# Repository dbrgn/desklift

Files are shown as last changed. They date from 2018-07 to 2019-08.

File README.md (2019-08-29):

# desklift

A simple PCB to control an Actiforce desk lift from a Blue Pill STM32
microcontroller board using two low-current relays.

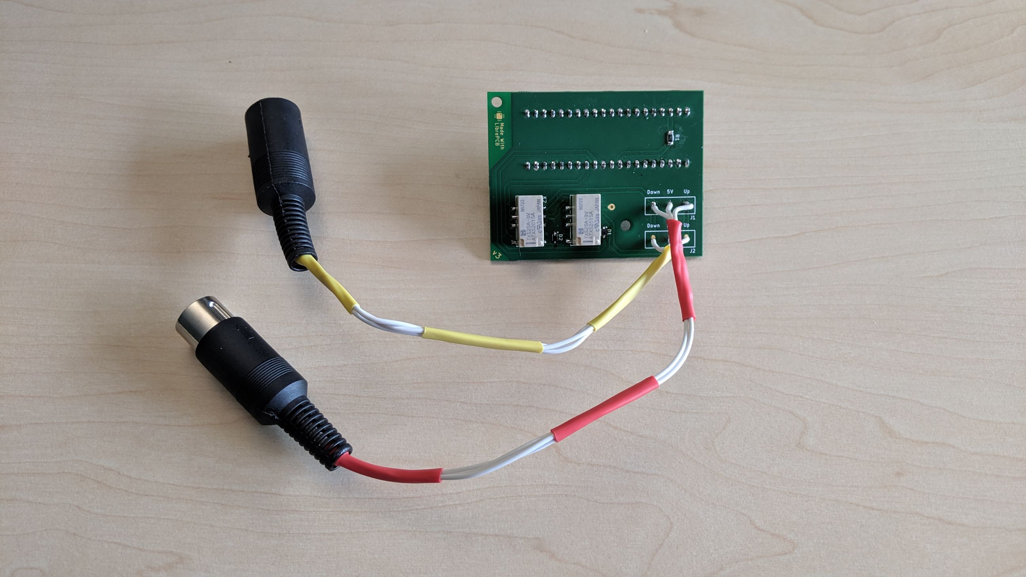
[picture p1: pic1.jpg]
Picture 1: Front


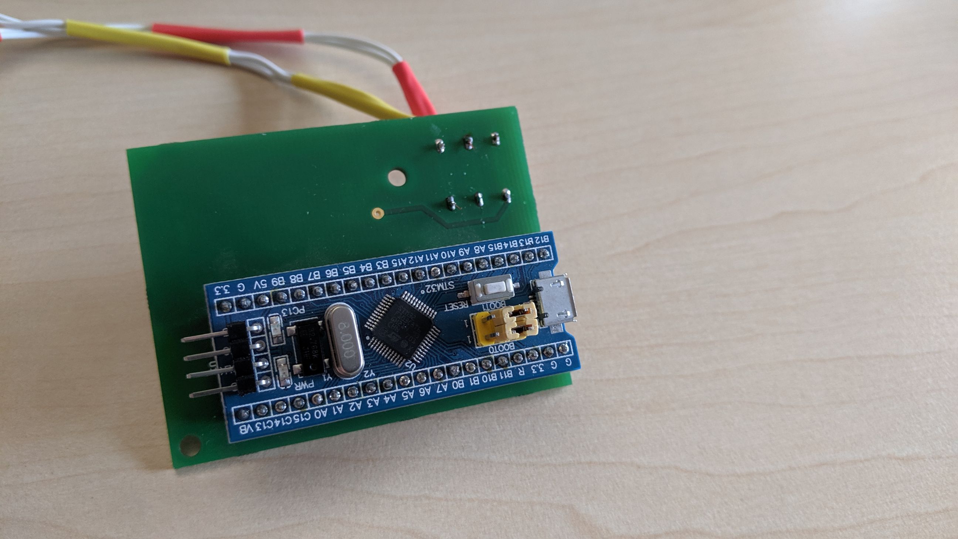
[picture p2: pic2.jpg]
Picture 2: Back


The PCB itself is designed mostly one-sided, you just need a single jumper wire
if you want a one-sided board. This makes it suitable for self-etching.

You can order the PCB [on Aisler](https://aisler.net/p/MNKNKKFU).

This is a [LibrePCB](http://librepcb.org) project!

## BOM

| Designator | Description | MPN | Approx. Cost |
| --- | --- | --- | --- |
| U1 | [STM32F103 "Blue Pill"](https://www.embedded-tools.ch/boards/stm/247/stm32f103c8t6-blue-pill-eval-board) | | 5.50 CHF |
| U1 | [Socket Strip 1x20](https://de.aliexpress.com/item/32996229462.html) | | 0.74 USD |
| K1, K2 | [Relay 3V 16.7mA](https://www.digikey.ch/product-detail/de/panasonic-electric-works/TXS2SA-3V/255-2341-5-ND/650160) | TXS2SA-3V | 4.56 CHF |
| J1 | [7-Pin DIN 45329 Connector M](https://de.aliexpress.com/item/32860020971.html) | | 0.37 USD |
| J2 | [7-Pin DIN 45329 Connector F](https://de.aliexpress.com/item/32860020971.html) | | 0.42 USD |
| D1, D2 | [Diode Schottky 30V 500mA](https://www.digikey.ch/product-detail/de/on-semiconductor/NSR0530HT1G/NSR0530HT1GOSCT-ND/5761654) | NSR0530HT1G | 0.16 CHF |
| R1 | Resistor 1.8K 3216 (1206) | | 0.02 CHF |
| PCB | [Printed Circuit Board](https://aisler.net/p/MNKNKKFU) | | 7.50 CHF |

Total material cost: ~24 USD

## License

See [LICENSE.txt](LICENSE.txt).

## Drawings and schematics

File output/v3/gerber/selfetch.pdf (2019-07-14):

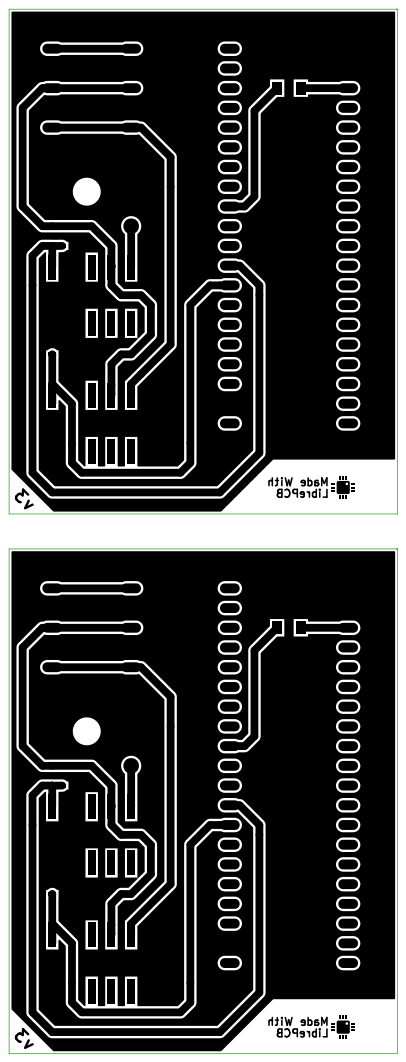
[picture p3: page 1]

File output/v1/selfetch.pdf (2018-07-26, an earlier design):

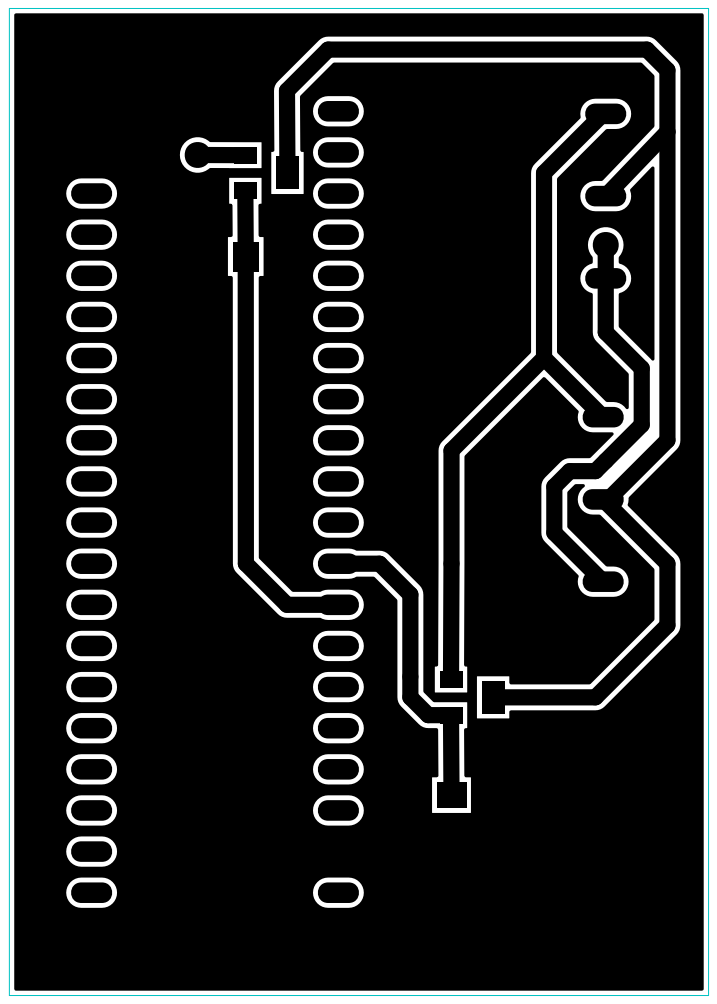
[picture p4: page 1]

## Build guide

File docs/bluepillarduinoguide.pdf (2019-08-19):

# STM32F103C8T6 Blue pill Arduino guide

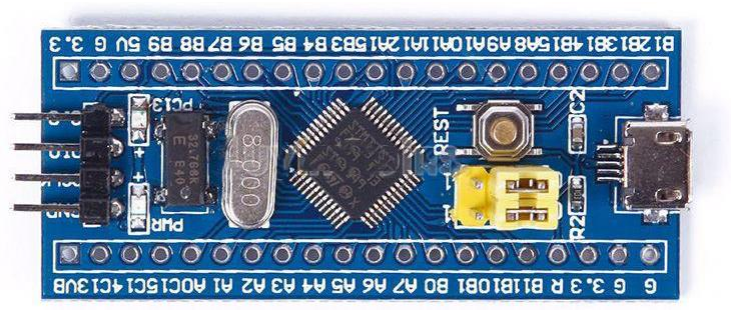
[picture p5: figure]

For beginners it might be difficult to use the popular and cheap blue pill board based on STM32F103C8T6. It’s because using an embedded development tools like KEIL isn’t easy for beginners. This 32 bit microcontroller based on ARM Cortex-M3 architecture is far better than your traditional arduino board.

You can compare it to Arduino DUE but it has got a very small size like the arduino Nano. There’s lack of proper documentation on it and everything available in the internet is quite scattered. So, here’s something to get you started easily.

## STEPS:

1. First download all the resources from this mediafire link. (http://www.mediafire.com/file/3h9gcih1budfhiz/resource_STM32_bluepill.zip) The password for extracting data from the zip file is: techshopbd.
2. Open resource STM32 bluepill folder. Copy the Arduino_STM32 folder to your sketchbook folder/hardware. Go to arduino IDEs file>preferences and you’ll find the location of your sketchbook folder. If there’s no hardware folder, create one named as “hardware” (all lowercase letter).Your arduino IDE is now ready for Blue pill.
3. Have a look on the pinout diagram on the next page. There are 2 yellow colored jumpers beside the usb port. They are boot options. Connect boot0 pin to 3V3 and boot1 pin to GND to start the board in SPI mode when it’s powered up or the reset button is pressed.
4. Now connect a FTDI board (FT232RL) to blue pill. You can use any of this (https://www.techshopbd.com/product-categories/breakout-boards/1771/ftdi-basic-breakout-3-3v-techshop-bangladesh) or this (https://www.techshopbd.com/product-categories/modules-98775/2621/ftdi-usb-to-serial-converter-3v3-5v-techshop-bangladesh) or this. (https://www.techshopbd.com/product-categories/modules-98775/2622/ftdi-usb-to-serial-converter-3v3-techshop-bangladesh) Connect FTDI TX to blue pill RX1 (PA10) and FTDI RX to blue pill TX1(PA9).
5. Connect GND. If your FTDI power pin is 5V, connect it to the 5v pin of Blue pill board. If it’s 3.3 volt, connect to the pin marked as 3.3. Connecting 5v to any 3.3v pin of Blue pill board will permanently damage it.

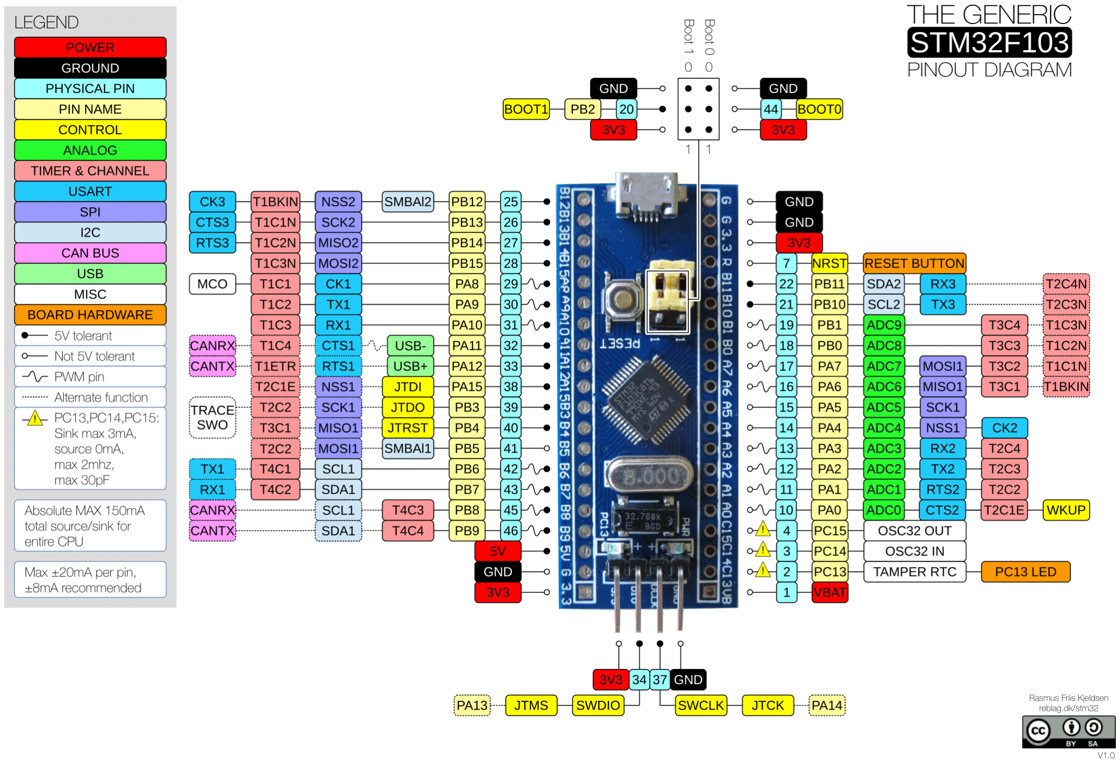
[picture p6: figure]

6. Connect the FTDI board to your PC using USB port. You must install the FTDI driver to your PC to use the FTDI board. You’ll find enough resources on the internet on this. FYI, it’s the driver for arduino Nano.
7. Close arduino IDE if it’s open. Then open it. Go to Tools>board> Generic STM32F103C Series. Then go to Tools>Variant>STM32F103C8T6(20k ram, 64k flash). These new options for STM32 will be automatically added to arduino if you’ve performed everything described it step 2 successfully.
8. Go to tools> upload method>serial. Then tools>port and select the port of the FTDI.
9. Go to tools>board> Boards manager and check if “Arduino SAM Boards (32 bit ARM Cortex M3)” is installed or not. If not, select more info and an install button will appear. Install the board definitions. It’s necessary because codes for the Blue pill board uses some files written for Arduino Duo for successful compilation.
10. Now open the blink code from File>Examples>Basic>blink. Press the reset button on the Blue pill board and hit upload button on the Arduino IDE. (board built-in LED is on PC13)
11. Note that you have to reset the Blue pill board every time you are about to upload code.

12. You will find all other Examples for the Blue pill board under Up button beneath tools option>hardware>Arduino_STM32.

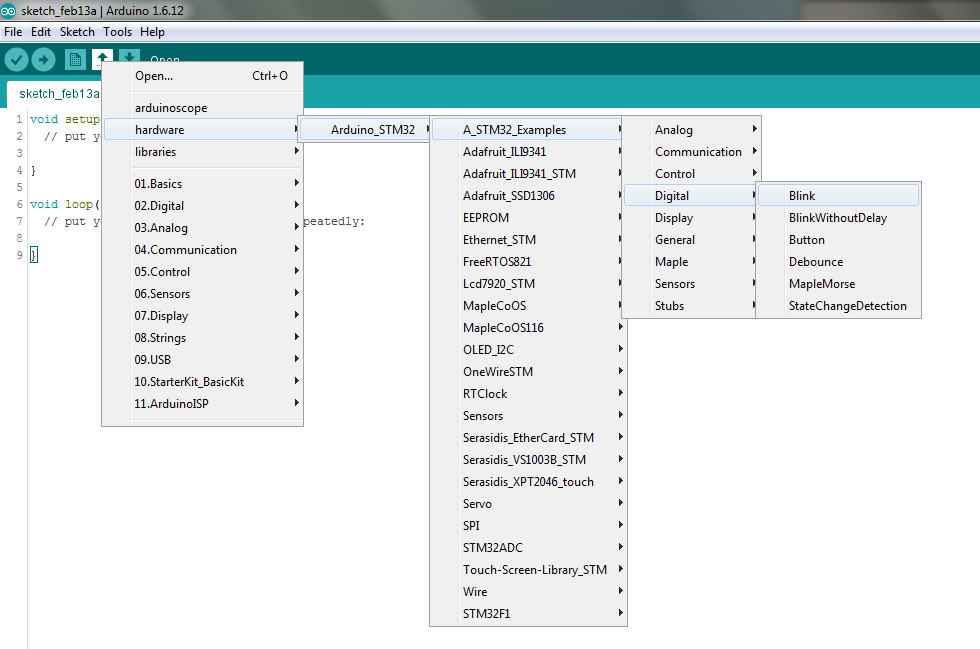
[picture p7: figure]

Note that, your code will stop working as soon as you restart or reset the blue pill board. You have to connect boot0 pin to GND using the jumper after uploading code to watch your code working. But you cannot upload code using USAR1 when boot0 is connected to GND. So,

1. Every time before uploading code, connect boot0 to 3V3 and press the reset button
2. When done with code uploading, connect boot0 to GND.

Uploading program directly to flash:

If you don’t want to use FTDI to upload code and use the microusb port of the blue Pill board instead, you have to flash a bootloader inside the STM32F103C8T6. By doing so, you don’t have to connect boot0 pin to 3v3 for uploading code. And there will be no need to press the RESET button every time before uploading a code.

1. Download demonstrator gui (STM32 flasher) from this link. (http://www.st.com/en/development-tools/flasher-stm32.html) You have to create a free account to download. Install the software when downloaded.
2. Keep your blue Pill board connected to PC via the FTDI and keep boot0 pin connected to 3V3. Press the RESET button.
3. Open STMFlashLoader Demo (demonstrator gui) executable file. Select 115200 Baud rate and select the FTDI COM port. Leave all other settings as default.
4. Press NEXT and It will automatically detect the blue pill.

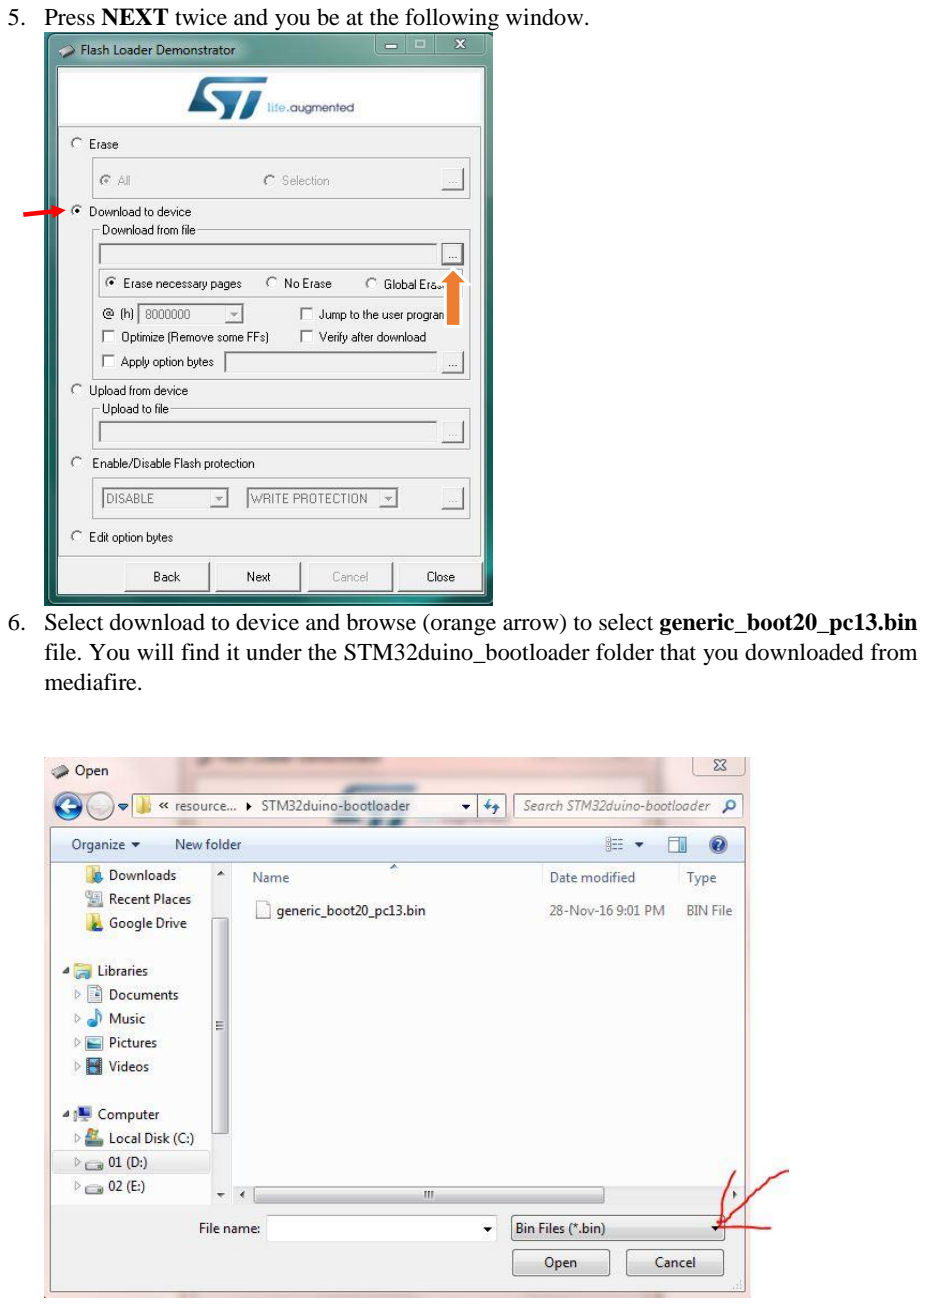
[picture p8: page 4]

5. Press NEXT twice and you be at the following window.
6. Select download to device and browse (orange arrow) to select generic_boot20_pc13.bin file. You will find it under the STM32duino_bootloader folder that you downloaded from mediafire.

7. Select Bin Files (red arrow) if the bootloader file doesn’t show up. Press Open.
8. Press NEXT when the bootloader file is loaded and the file will be downloaded to Blue pill board. Close demonstrator gui (STM32 flasher) when done.
9. Open your arduino sketchbook folder. Then open Arduino_STM32 folder>drivers>win and run “install_drivers.bat” as administrator (right click on file, then select run as administrator). Press any key to close when done.
Then run “install_STM_COM_drivers.bat” as administrator, too.
10. Connect boot0 to GND, disconnect FTDI board and connect a microUSB cable (android data cable) to Blue pill. Press the RESET button before connecting to PC.
11. You’ll find windows installing driver for the Blue pill when you connect it to PC using the on board microUSB. Eventually a driver named as “maple DFU” will be installed. You can find it inside windows Device Manager>libusb>maple DFU. Note that there will be no COM port assigned to Blue pill board. That’s normal.
12. Open arduino IDE. Go to Tools>board> Generic STM32F103C Series. Then go to Tools>Variant>STM32F103C8T6 (20k ram, 64k flash). Go to tools> upload
method>STM32duino | bootloader. | Now | open | the | blink | code | from
File>Examples>Basic>blink.
13. Go to tools>port and make sure no port is selected or the port option is deactivated.
14. Hit the upload button. As soon as “uploading” message appears at the bottom of arduino IDE, press the RESET button of Blue pill board.
15. If your code uploads successfully, you’ll find that windows is installing a new driver and this time it will assign a COM port for your Blue pill board.
16. Go to tools>port and select the correct COM port for Blue pill. The COM port can be found on windows Device Manager> ports (COM & LPT)> Maple Serial (correct port).
17. You have to make sure that the correct COM port is selected to ensure code uploading from now on.

The STM32duino bootloader is called perpetual bootloader. It works on DFU mode at first without using any COM port. After the first program is uploaded, it assigns COM port for the computer.

18. You are now ready to use Blue pill board as normal arduino board by using the on board microUSB. Keep Boot0 and Boot1 pin always connected to GND. You don’t have to press RESET button while uploading code anymore.

Video Resources:
www.youtube.com/watch?v=Ze6q6NidS5w www.youtube.com/watch?v=0jdJp3TQuJY

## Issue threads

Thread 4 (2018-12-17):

Implement USB support

dbrgn, 2018-12-17:
...using https://github.com/mvirkkunen/stm32f103xx-usb

dbrgn, 2019-08-18:
Replaced by https://github.com/stm32-rs/stm32-usbd

Closed 2019-08-21.

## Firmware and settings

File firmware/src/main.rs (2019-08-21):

//! Desk lift firmware
//!
//! Serial protocol:
//!
//! - Baudrate 115'200
//! - Every command is a single signed byte
//! - Positive values move up, negative values move down
//! - The value must be multiplied by 10 ms to get the move duration
//!
//! Physical wiring:
//!
//! - Serial communication over USART1 (PB6, PB7)
//! - "Up" connected to PB4
//! - "Down" connected to PB5

#![deny(unsafe_code)]
#![no_main]
#![cfg_attr(not(test), no_std)]

// Panicking behavior
#[cfg(not(feature = "debug"))]
extern crate panic_halt; // you can put a breakpoint on `rust_begin_unwind` to catch panics
#[cfg(feature = "debug")]
extern crate panic_semihosting; // logs messages to the host stderr; requires a debugger

// Debug logging
#[cfg(feature = "debug")]
use cortex_m_semihosting::hprintln;

use cortex_m::asm::delay;
use embedded_hal::digital::v2::OutputPin;
use rtfm::app;
use stm32_usbd::{UsbBus, UsbBusType};
use stm32f1xx_hal::{prelude::*, pac};
use stm32f1xx_hal::delay::{Delay};
use stm32f1xx_hal::gpio::{Output, PushPull, OpenDrain, State, gpiob, gpioc};
use usb_device::bus;
use usb_device::device::UsbDevice;
use usb_device::prelude::{UsbDeviceBuilder, UsbVidPid};
use usbd_serial::{SerialPort, USB_CLASS_CDC};

use desklift_command::{Command, Direction};

const ERRNO_GPIO_UPDN: u8 = 1;
const ERRNO_GPIO_LED: u8 = 2;
const ERRNO_GPIO_DEBUG: u8 = 3;

const VERSION: &str = env!("CARGO_PKG_VERSION");

#[app(device = stm32f1::stm32f103)]
const APP: () = {
    // GPIO pins
    static mut GPIO_UP: gpiob::PB4<Output<PushPull>> = ();
    static mut GPIO_DOWN: gpiob::PB5<Output<PushPull>> = ();

    // LED pins
    static mut LED: gpioc::PC13<Output<OpenDrain>> = ();

    // Delay peripheral
    static mut DELAY: Delay = ();

    // USB
    static mut USB_DEV: UsbDevice<'static, UsbBusType> = ();
    static mut USB_SERIAL: SerialPort<'static, UsbBusType> = ();

    /// Initialiation happens here.
    ///
    /// The init function will run with interrupts disabled and has exclusive
    /// access to Cortex-M and device specific peripherals through the `core`
    /// and `device` variables, which are injected in the scope of init by the
    /// app attribute.
    #[init]
    fn init() {
        static mut USB_BUS: Option<bus::UsbBusAllocator<UsbBusType>> = None;

        #[cfg(feature = "debug")]
        hprintln!("init").unwrap();

        // Cortex-M peripherals
        let core: rtfm::Peripherals = core;

        // Device specific peripherals
        let device: pac::Peripherals = device;

        // Get reference to peripherals required for USART
        let mut rcc = device.RCC.constrain();
        let mut afio = device.AFIO.constrain(&mut rcc.apb2);
        let mut gpioa = device.GPIOA.split(&mut rcc.apb2);
        let mut gpiob = device.GPIOB.split(&mut rcc.apb2);
        let mut gpioc = device.GPIOC.split(&mut rcc.apb2);
        let mut flash = device.FLASH.constrain();
        let clocks = rcc
            .cfgr
            .use_hse(8.mhz())
            .sysclk(48.mhz())
            .pclk1(24.mhz())
            .freeze(&mut flash.acr);
        assert!(clocks.usbclk_valid());

        // Disable JTAG to free up pins PA15, PB3 and PB4 for normal use
        let (_pa15, _pb3, pb4) = afio.mapr.disable_jtag(gpioa.pa15, gpiob.pb3, gpiob.pb4);

        // BluePill board has a pull-up resistor on the USB D+ line.
        // Pull the D+ pin down to send a RESET condition to the USB bus.
        let mut usb_dp = gpioa.pa12.into_push_pull_output(&mut gpioa.crh);
        usb_dp.set_low().unwrap();
        delay(clocks.sysclk().0 / 100);

        // Initialize USB bus
        let usb_dm = gpioa.pa11;
        let usb_dp = usb_dp.into_floating_input(&mut gpioa.crh);
        *USB_BUS = Some(UsbBus::new(device.USB, (usb_dm, usb_dp)));

        // Initialize serial port over USB
        let usb_serial = SerialPort::new(USB_BUS.as_ref().unwrap());

        // Create USB device
        let usb_dev = UsbDeviceBuilder::new(USB_BUS.as_ref().unwrap(), UsbVidPid(0x16c0, 0x27dd))
            .manufacturer("dbrgn")
            .product("Desklift v3")
            .serial_number(VERSION)
            .device_class(USB_CLASS_CDC)
            .build();

        // Set up GPIO outputs
        let mut gpio_up = pb4.into_push_pull_output(&mut gpiob.crl);
        let mut gpio_down = gpiob.pb5.into_push_pull_output(&mut gpiob.crl);
        gpio_up.set_low().unwrap();
        gpio_down.set_low().unwrap();

        // Set up delay provider
        let mut delay = Delay::new(core.SYST, clocks);

        // Set up status LED and blink twice
        let mut led = gpioc.pc13.into_open_drain_output_with_state(&mut gpioc.crh, State::High);
        led.set_low().unwrap();
        delay.delay_ms(200u16);
        led.set_high().unwrap();
        delay.delay_ms(200u16);
        led.set_low().unwrap();
        delay.delay_ms(200u16);
        led.set_high().unwrap();

        // Assign resources
        GPIO_UP = gpio_up;
        GPIO_DOWN = gpio_down;
        LED = led;
        DELAY = delay;
        USB_DEV = usb_dev;
        USB_SERIAL = usb_serial;
    }

    // /// The runtime will execute the idle task after init. Unlike init, idle
    // /// will run with interrupts enabled and it's not allowed to return so it
    // /// runs forever.
    // #[idle]
    // fn idle() -> ! {
    //     #[cfg(feature = "debug")]
    //     hprintln!("idle").unwrap();
    //
    //     // Busy-loop. In production, remove the `idle` function to fall back to
    //     // the default implementation which puts the device to sleep.
    //     loop {}
    // }

    #[interrupt(resources = [USB_DEV, USB_SERIAL, GPIO_UP, GPIO_DOWN, DELAY, LED])]
    fn USB_LP_CAN_RX0() {
        usb_poll(
            &mut resources.USB_DEV,
            &mut resources.USB_SERIAL,
            &mut resources.GPIO_UP,
            &mut resources.GPIO_DOWN,
            &mut resources.DELAY,
            &mut resources.LED,
        );
    }

    // RTFM requires that free interrupts are declared in an extern block when
    // using software tasks; these free interrupts will be used to dispatch the
    // software tasks.
    extern "C" {
        fn SPI1();
        fn SPI2();
    }
};

fn usb_poll<B: bus::UsbBus>(
    usb_dev: &mut UsbDevice<'static, B>,
    serial: &mut SerialPort<'static, B>,
    gpio_up: &mut gpiob::PB4<Output<PushPull>>,
    gpio_down: &mut gpiob::PB5<Output<PushPull>>,
    delay: &mut Delay,
    led: &mut gpioc::PC13<Output<OpenDrain>>,
) {
    if !usb_dev.poll(&mut [serial]) {
        return;
    }

    let mut buf = [0u8; 8];

    match serial.read(&mut buf) {
        Ok(count) if count > 0 => {
            // Echo back in upper case
            for byte in &buf[0..count] {
                let command = Command::from_u8(*byte);
                match move_table(command, gpio_up, gpio_down, delay, led) {
                    Ok(_) => serial.write(&[0]).ok(),
                    Err(errno) => serial.write(&[errno]).ok(),
                };
            }
        }
        _ => {}
    }
}

fn move_table(
    command: Command,
    gpio_up: &mut gpiob::PB4<Output<PushPull>>,
    gpio_down: &mut gpiob::PB5<Output<PushPull>>,
    delay: &mut Delay,
    led: &mut gpioc::PC13<Output<OpenDrain>>,
) -> Result<(), u8> {
    #[cfg(feature = "debug")]
    hprintln!("Move: {}", command).map_err(|_| ERRNO_GPIO_DEBUG)?;
    match command.get_direction() {
        Direction::Up => gpio_up.set_high().map_err(|_| ERRNO_GPIO_UPDN)?,
        Direction::Down => gpio_down.set_high().map_err(|_| ERRNO_GPIO_UPDN)?,
    };
    led.set_low().map_err(|_| ERRNO_GPIO_LED)?;
    delay.delay_ms(command.get_ms());
    gpio_up.set_low().map_err(|_| ERRNO_GPIO_UPDN)?;
    gpio_down.set_low().map_err(|_| ERRNO_GPIO_UPDN)?;
    led.set_high().map_err(|_| ERRNO_GPIO_LED)?;
    Ok(())
}

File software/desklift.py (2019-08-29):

#!/usr/bin/env python3

import ctypes
import math
import sys

import serial


DEV = '/dev/ttyACM0'
BAUD = 115200


def make_commands(direction: str, milliseconds: int) -> bytes:
    assert milliseconds > 0, 'Duration may not be negative'
    steps = milliseconds // 10
    sign = 1 if direction == 'up' else -1
    cmd_max = 127
    iterations = math.ceil((steps + 1) / 127)
    commands = []
    for i in range(iterations):
        if i + 1 < iterations:
            commands.append(ctypes.c_ubyte(cmd_max * sign).value)
        elif (steps % cmd_max) > 0:
            commands.append(ctypes.c_ubyte((steps % cmd_max) * sign).value)
    return commands


def main(direction: str, milliseconds: int):
    assert milliseconds <= 15000, 'Duration may not be larger than 15 seconds'
    desklift = serial.Serial(DEV, baudrate=BAUD)
    commands = make_commands(direction, milliseconds)
    desklift.write(bytes(commands))


if __name__ == '__main__':
    if len(sys.argv) != 3 or sys.argv[1] not in ['up', 'down']:
        print('Usage: {} (up|down) <milliseconds>'.format(sys.argv[0]))
        sys.exit(1)
    main(sys.argv[1], int(sys.argv[2]))

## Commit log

2018-07-24 Add groundplane
2018-07-26 Update library & traces
2018-07-26 Add v1 output
    [desklift.gbl, desklift.gbo, desklift.gbs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]
2018-07-30 V2 routing
    [desklift.gbl, desklift.gbo, desklift.gbs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]
2018-08-07 Add FlatCAM project and G-Code files of PCB V2 (#2)
2018-08-15 firmware: Initial structure
    [jlink-swd.cfg]
2018-08-30 firmware: Switch to rust-lld
2018-11-08 firmware: Switch ringthing to Rust 2018
2018-11-08 firmware: Switch to Rust 2018
2018-11-08 firmware: Start playing around with rtfm based prototype
2018-11-08 firmware: Replace ring buffer with task capacity
    [main.rs]
2018-11-09 firmware: Read a byte from serial on UART1 interrupt
2018-12-11 firmware: Fixes and updates
    [main.rs]
2019-04-19 pcb: Add relays
2019-05-09 pcb: Get rid of MOSFET
    I found different relays that can be triggered directly with the I/O
    pins.
2019-05-11 pcb: Update library elements
2019-05-11 Remove PCB variant
2019-05-11 pcb: Routing
2019-07-13 pcb: v3
2019-07-13 pcb: Update library
2019-07-13 pcb: Add LibrePCB logo
2019-07-14 pcb: Add v3 output
    [desklift_COPPER-BOTTOM.gbr, desklift_COPPER-TOP.gbr, desklift_DRILLS.drl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]
2019-08-17 firmware: Port to stm32 crates by stm32-rs (fixes #7)
    [main.rs]
2019-08-18 firmware: Fix GPIO configuration, add status LED
    [main.rs]
2019-08-21 firmware: Use VERSION as usb device version
2019-08-29 pcb: Tweak placement layer
2019-08-29 Add BOM and pictures
